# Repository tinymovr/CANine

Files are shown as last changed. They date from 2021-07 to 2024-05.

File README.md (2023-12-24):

# CANine Schematics, Drawings and Firmware

## Schematics and Drawings

CANine is Certified Open Source Hardware

[OSHW] GR000007 | Certified open source hardware | oshwa.org/cert

## Firmware

USB CDC firmware for the CANine USB⟷CAN Bus adapter. This firmware is based on slcan but gets rid of the Virtual Com Port cruft, resulting in leaner communication on all platforms, and especially on Windows. Most slcan commands are the same, but the CAN frame size is fixed and data is transmitted as binary (instead of ascii in slcan).

This firmware should be compatible with CANable adapters, but has not been tested.

[Documentation](https://canine.readthedocs.io/en/latest/)

### Flashing

We now offer [a simple Web-based firmware update service](https://tinymovr.github.io/CANine/). Instructions are available on the page. Chrome and Edge are supported.

### Using

This firmware is compatible with python-can through the corresponding [plugin available on PyPi](https://pypi.org/project/python-can-canine/).

This firmware is compatible with Tinymovr. To use with Studio, add the command line parameter `--bus=canine` when launching.

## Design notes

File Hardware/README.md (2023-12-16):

# CANine CAN Adapter

This is a USB Type-C <-> CAN Bus adapter. Itself it is an adaptation of the [CANable board](https://canable.io/). It features a 2.54mm screw terminal, a 4-pin JST-GH connector, and a 2.54mm header. In addition, it features a convenient DIP switch for setting CAN termination resistor and boot mode.

This design is released under the original CANable license.

This directory also includes an STL model for a compact 3D printable case.

There is also an [alternative case design for the legacy CANine](https://github.com/ThotAlion/BLDC-design-help/tree/main/STL/USBCANBox) by ThotAlion.

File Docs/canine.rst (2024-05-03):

**********************
CANine adapter
**********************

Introduction
############

This is a USB Type-C <-> CAN Bus adapter. Itself it is an adaptation of the [CANable board](https://canable.io/). It features a 5.08mm screw terminal, a 4-pin JST-GH connector, and a 2.54mm header. In addition, it features a convenient DIP switch for setting CAN termination resistor and boot mode.

CANine includes the following hardware:

* STM32F042C6 MCU
* MCP2551 CAN Bus Transceiver
* JST-GH/5.08mm Screw Terminal/2.54mm Pin header CAN interfaces
* USB Type-C (v2) / micro (v1) interface

This design is Open Source, released under the original CANable license.

Hardware Configuration
######################

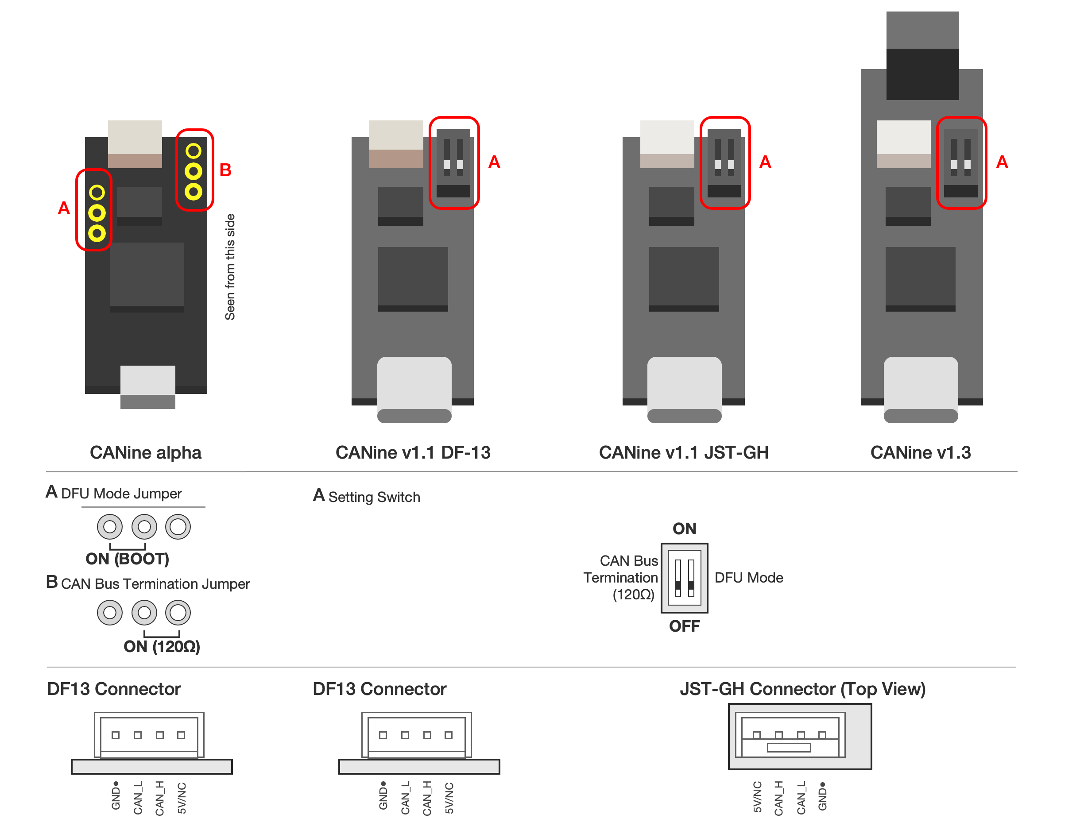
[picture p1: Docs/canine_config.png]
CANine hardware configuration diagram


.. warning::
   * Do not change the position of the DIP switches while the adapter is powered. First remove power, perform your change, and power back on.

CAN Termination Resistor
------------------------

CANine includes a termination resistor to ease the setup of a CAN Bus network. If CANine is a terminal node in the network, you should enable the 120Ohm termination resistor via the onboard DIP switch. In small setups with a few nodes and short wires, it is enough to enable just a single termination resistor, either on the CANine or on a single Tinymovr.

Flashing Firmware
#################

CANine comes pre-flashed with `slcan <https://python-can.readthedocs.io/en/master/interfaces/slcan.html>`_.

Hardware Preparation
--------------------

Unplug the CANine adapter from USB. Flip the DFU switch to the ON position. Plug the adapter back into USB. The device will appear as a ST DFU Device, and allow firmware flashing. Once firmware flashing is complete, unplug the device and return the switch to the OFF position.

CANine Firmware
---------------

To try the CANine firmware, we offer `a simple Web-based firmware update service <https://tinymovr.github.io/CANine/>`_. Instructions are available on the page. Chrome and Edge are supported.

Python-Can Compatibility
************************

We offer a `python-can plugin available on PyPi <https://pypi.org/project/python-can-canine>`_, which allows use of CANine with python-can. The plugin is easily installable via pypi:

.. code-block:: console

    pip install python-can-canine

To use with Tinymovr Studio, add the command line parameter `--bus=canine` when launching.

In your scripts, use the CANine interface through a simple import:

.. code-block:: python

    import can
    from canine import CANineBus
    
    bus = can.Bus(interface="canine", bitrate=1000000)

Additional Windows Requirements
*******************************

You will need to install the libusb driver for your CANine. This is most easily done using `Zadig <https://zadig.akeo.ie>`_

Additional Macos Requirements
*****************************

You will need to install libusb. This can be easily done using `Homebrew <https://brew.sh>`_:

.. code-block:: console

    brew install libusb

In ARM-based Macs you may also need to link the homebrew library install path to the fallback path `/lib`. This can be done with the following command:

.. code-block:: console

    ln -s /opt/homebrew/lib ~/lib

Additional Linux requirements
*****************************

You will need to add udev rules for CANine:

.. code-block:: console

    sudo bash -c 'echo -e "SUBSYSTEM==\"usb\", ATTR{idVendor}==\"0483\", ATTR{idProduct}==\"c1b0\", MODE=\"0666\", SYMLINK+=\"canine_usb\"" > /etc/udev/rules.d/11-canine.rules'
    sudo udevadm control --reload-rules && sudo udevadm trigger

To have the rules loaded at every boot, add the command to your `.bashrc`.

slcan & CANdlelight Firmware
----------------------------

CANine is compatible with both slcan as well as candlelight firmware. If you would like to revert to these firmwares, the easiest solution is to use the `canable updater <https://canable.io/updater/>`_. Similarly to the CANine flasher, this updater works directly from within the browser. Chrome and Edge are supported.

3D Printed Case Assembly
########################

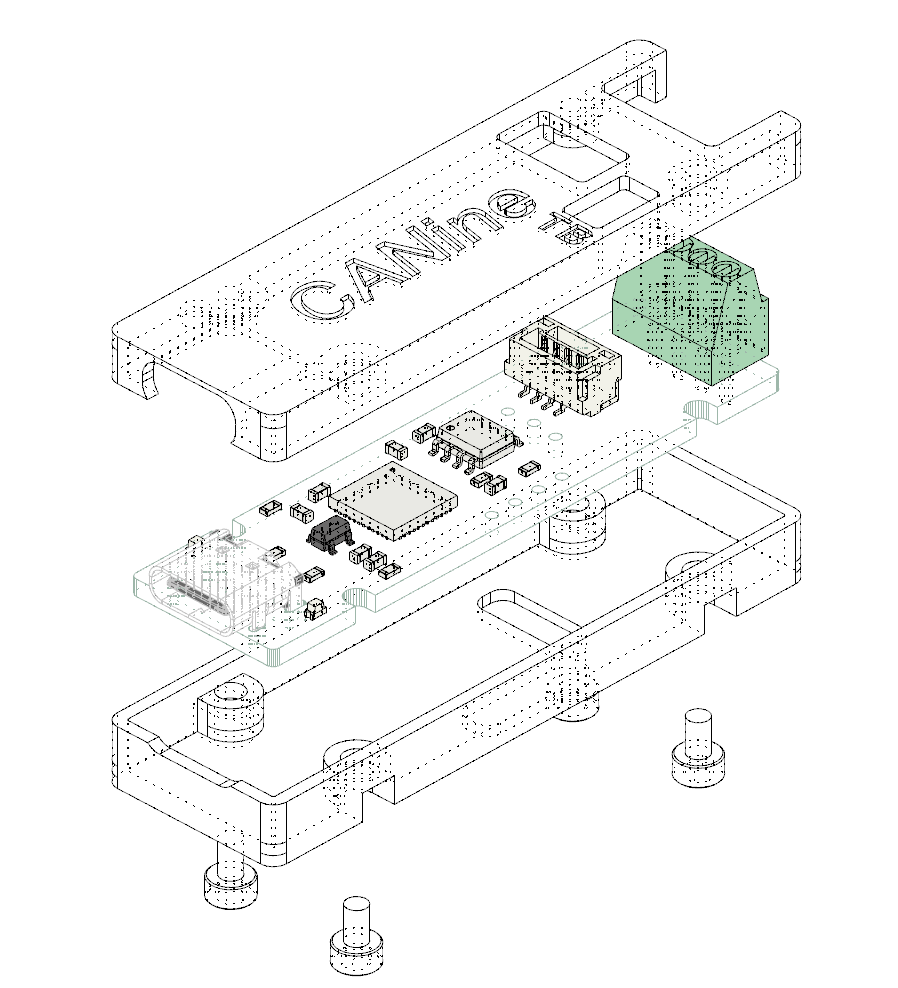
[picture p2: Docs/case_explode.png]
CANine 3D Printed Case


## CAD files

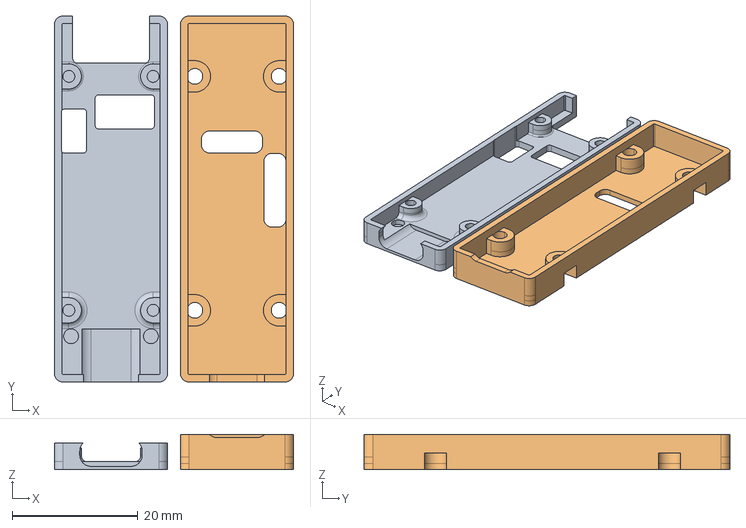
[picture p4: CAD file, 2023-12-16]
Hardware/CANine Cover.stp
38.1 x 58.2 x 5.58 mm

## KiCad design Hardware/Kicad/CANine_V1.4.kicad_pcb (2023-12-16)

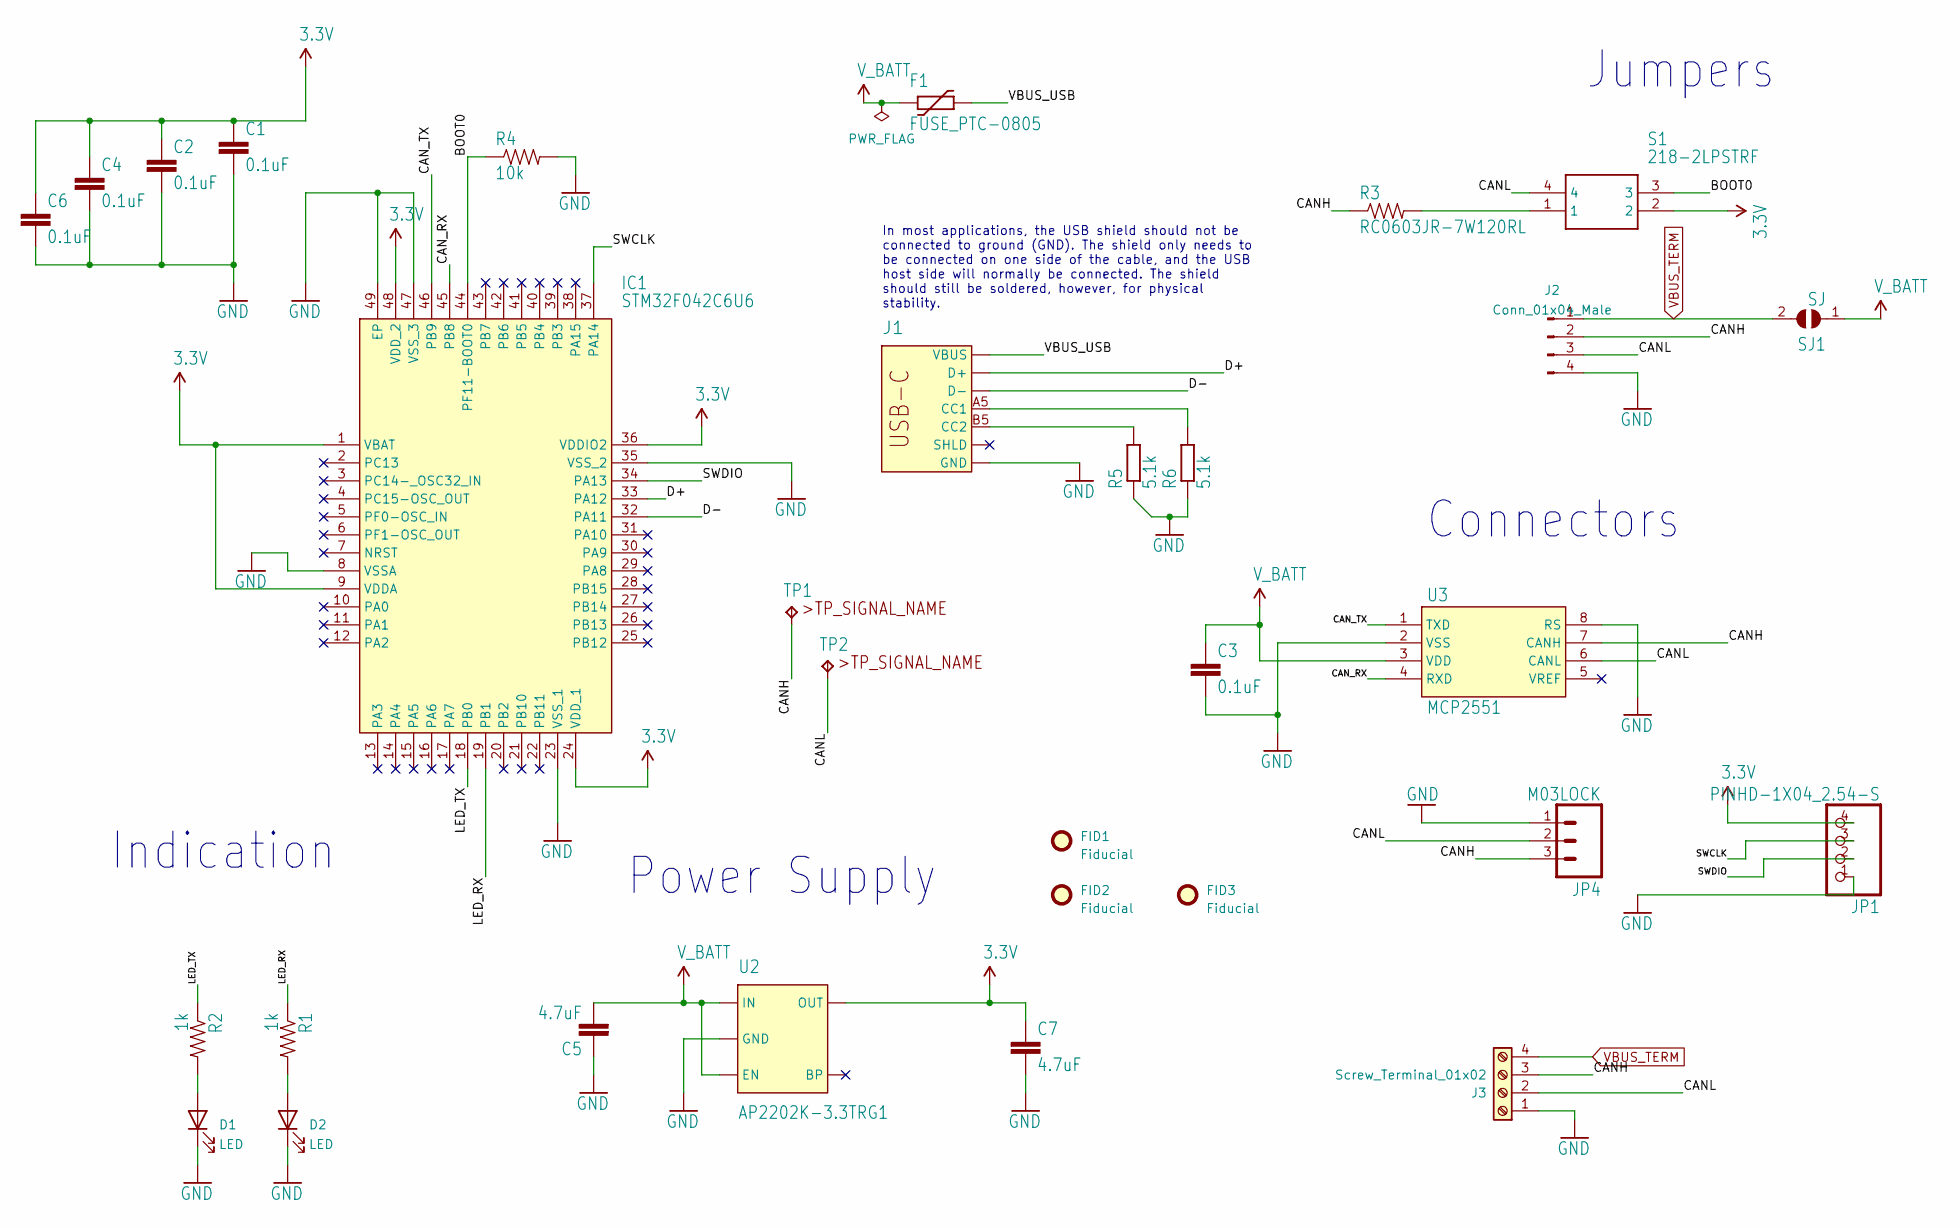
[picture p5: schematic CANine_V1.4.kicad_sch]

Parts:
C1, C2, C3, C4, C6: 0.1uF; C_0603_1608Metric
C5, C7: 4.7uF; C_0603_1608Metric
D1, D2: LED; LED_0603_1608Metric
F1: FUSE_PTC-0805; PTC0805
FID1, FID2, FID3: Fiducial; Fiducial_0.75mm_Mask1.5mm
IC1: STM32F042C6U6; QFN-48-1EP_7x7mm_P0.5mm_EP5.6x5.6mm
J1: SPARKFUN-CONNECTORS_USB_C16PIN; SPARKFUN-CONNECTORS_USB-C-16P
J2: Conn_01x04_Male; JST_GH_BM04B-GHS-TBT_1x04-1MP_P1.25mm_Vertical
J3: Screw_Terminal_01x02; TerminalBlock_Phoenix_MPT-0,5-4-2.54_1x04_P2.54mm_Horizontal
JP1: PINHD-1X04_2.54-S; 1X04-S
JP4: M03LOCK; 1X03_LOCK
R1, R2: 1k; R_0603_1608Metric
R3: RC0603JR-7W120RL; R_0603_1608Metric
R4: 10k; R_0603_1608Metric
R5, R6: 5.1k; R_0603_1608Metric
S1: 218-2LPSTRF; 2182LPSTRF
SJ1: SJ
TP1, TP2: TPTP16R; TP16R
U2: AP2202K-3.3TRG1; SOT-23-5
U3: MCP2551; SOIC-8_3.9x4.9mm_P1.27mm

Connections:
3.3V: C1.1, C2.1, C4.1, C6.1, C7.1, IC1.1 (VBAT), IC1.9 (VDDA), IC1.24 (VDD_1), IC1.36 (VDDIO2), IC1.48 (VDD_2), JP1.4, S1.2, U2.5 (OUT)
/BOOT0: IC1.44 (PF11-BOOT0), R4.1, S1.3
/CANH: J2.2, J3.3, JP4.3, R3.1, TP1.TP, U3.7 (CANH)
/CANL: J2.3, J3.2, JP4.2, S1.4, TP2.TP, U3.6 (CANL)
/CAN_RX: IC1.45 (PB8), U3.4 (RXD)
/CAN_TX: IC1.46 (PB9), U3.1 (TXD)
/D+: IC1.33 (PA12), J1.A6 (D+), J1.B6 (D+)
/D-: IC1.32 (PA11), J1.A7 (D-), J1.B7 (D-)
/LED_RX: IC1.19 (PB1), R1.1
/LED_TX: IC1.18 (PB0), R2.1
/SWCLK: IC1.37 (PA14), JP1.3
/SWDIO: IC1.34 (PA13), JP1.2
/VBUS_USB: F1.2, J1.VBUS1 (VBUS), J1.VBUS2 (VBUS)
GND: C1.2, C2.2, C3.2, C4.2, C5.1, C6.2, C7.2, D1.1 (K), D2.1 (K), IC1.8 (VSSA), IC1.23 (VSS_1), IC1.35 (VSS_2), IC1.47 (VSS_3), IC1.49 (EP), J1.GND, J1.GND2 (GND), J2.4, J3.1, JP1.1, JP4.1, R4.2, R5.1, R6.1, U2.2 (GND), U3.2 (VSS), U3.8 (RS)
unnamed: D1.2 (A), R2.2
unnamed: D2.2 (A), R1.2
unnamed: J1.A5 (CC1), R6.2
unnamed: J1.B5 (CC2), R5.2
unnamed: R3.2, S1.1
VBUS_TERM: J2.1, J3.4, SJ1.2
V_BATT: C3.1, C5.2, F1.1, SJ1.1, U2.1 (IN), U2.3 (EN), U3.3 (VDD)

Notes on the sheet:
Jumpers
In most applications, the USB shield should not be connected to ground (GND). The shield only needs to be connected on one side of the cable, and the USB host side will normally be connected. The shield should still be soldered, however, for physical stability.
Connectors
Indication
Power Supply

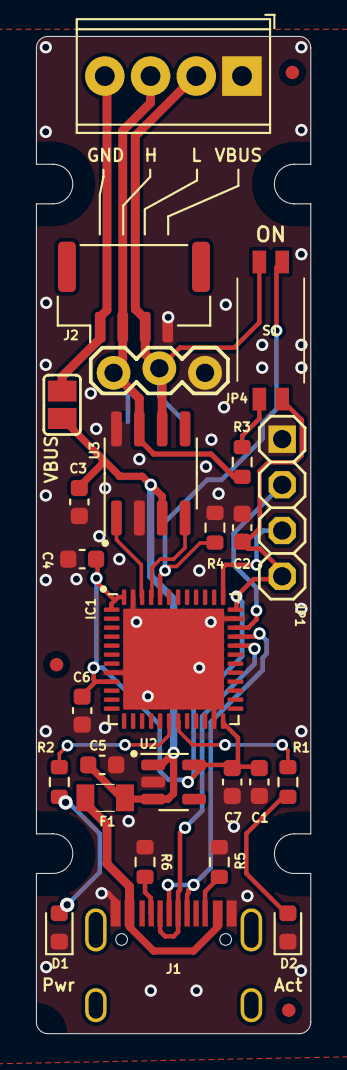
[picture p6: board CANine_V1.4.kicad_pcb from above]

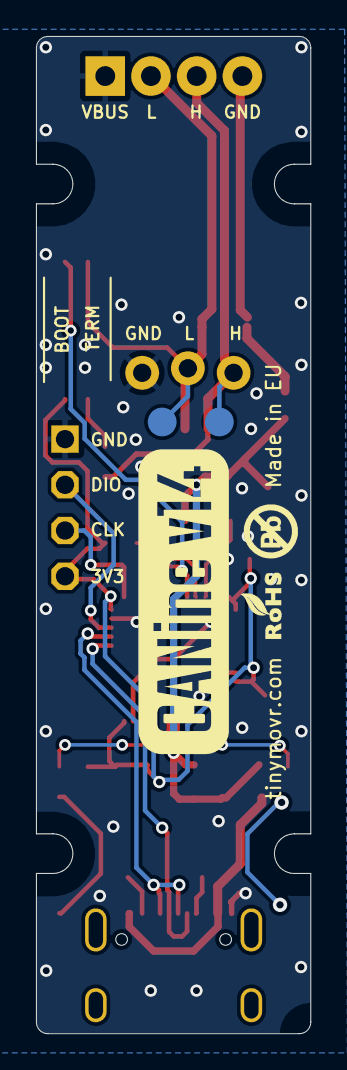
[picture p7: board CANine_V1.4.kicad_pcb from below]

Board: 2 copper layers, 15.2 x 55.4 mm, 31 parts (2 on the bottom side), 21 nets.

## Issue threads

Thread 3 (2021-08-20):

Raise can0 network with Canine on Linux

ThotAlion, 2021-08-20:
We did upgrade the firmware of the CANine dongle.
After plugging the dongle on the robot, no can0 interface appear on 'ifconfig'
Is there a command line to execute to create this network entry ? (like candlelight?) or is it automatic ?
And if we have two dongles, how to differenciate them ? Would you have an example or explain in the doc the process to create such udev rule ?

Thank you for your help,

yconst, 2021-08-20:
When you mention "upgraded", I assume you mean flashing the Candlelight firmware, correct? Because the firmware hosted in this repo is not compatible with socketcan, it is usb only.

You can follow the guide in the Canable page: https://canable.io/getting-started.html#alt-firmware

ThotAlion, 2021-08-20:
No, I mean I wanted to flash the firmware on this repo. I though it was a socketcan.
Therefore, this firmware shall open a /dev/ttyUSBX file ?
Thanks again.

yconst, 2021-08-21:
It only enumerates as a USB device, there is no serial interface. Currently it is supported by our [fork of the python-can library](https://github.com/tinymovr/python-can) (the `develop` branch). It's not yet tested on Linux (Windows and Macos works), but it should work without an issue.

You can set `--bustype=canine` for Tinymovr studio to use this protocol. In fact, if you pip install studio from the [main branch](https://github.com/tinymovr/Tinymovr), you'll get the forked python-can library installed automatically.

yconst, 2023-04-24:
Closing this as inactive

Closed 2023-04-24.

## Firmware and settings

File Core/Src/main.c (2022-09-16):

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
/* Includes ------------------------------------------------------------------*/
#include "main.h"
#include "usb_device.h"

/* USER CODE BEGIN Includes */
#include "stm32f0xx.h"
#include "stm32f0xx_hal.h"

#include "usb_device.h"
#include "usbd_cdc_if.h"
#include "can.h"
#include "slcan.h"
#include "led.h"
#include "error.h"
/* USER CODE END Includes */

CAN_HandleTypeDef hcan;

void SystemClock_Config(void);
static void MX_GPIO_Init(void);
static void MX_CAN_Init(void);
/**
  * @brief  The application entry point.
  * @retval int
  */
int main(void)
{
    /* MCU Configuration--------------------------------------------------------*/

    /* Reset of all peripherals, Initializes the Flash interface and the Systick. */
    HAL_Init();

    /* USER CODE BEGIN Init */
    can_init();
    /* USER CODE END Init */

    /* Configure the system clock */
    SystemClock_Config();

    /* Initialize all configured peripherals */
    MX_GPIO_Init();
    // MX_CAN_Init();
    MX_USB_DEVICE_Init();
    /* USER CODE BEGIN 2 */

    HAL_GPIO_WritePin(LED_GREEN, 1);
    led_blue_blink(2);

    // Storage for status and received message buffer
    CAN_RxHeaderTypeDef rx_msg_header;
    uint8_t rx_msg_data[8] = {0};
    uint8_t msg_buf[SLCAN_MTU];

    /* USER CODE END 2 */

    /* Infinite loop */
    /* USER CODE BEGIN WHILE */
    while (1)
    {
        cdc_process();
        led_process();
        can_process();

        // If CAN message receive is pending, process the message
        if(is_can_msg_pending(CAN_RX_FIFO0))
        {
            // If message received from bus, parse the frame
            if (can_rx(&rx_msg_header, rx_msg_data) == HAL_OK)
            {
                uint16_t msg_len = slcan_parse_frame((uint8_t *)&msg_buf, &rx_msg_header, rx_msg_data);

                // Transmit message via USB-CDC
                if(msg_len)
                {
                    CDC_Transmit_FS(msg_buf, msg_len);
                }
            }
        }
        /* USER CODE END WHILE */

        /* USER CODE BEGIN 3 */
    }
    /* USER CODE END 3 */
}

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


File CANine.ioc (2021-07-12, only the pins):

Mcu.UserName=STM32F042C6Tx
PA13.Signal=SYS_SWDIO
PA12.Signal=USB_DP
PB9.Signal=CAN_TX
PB1.Signal=GPIO_Output
PA11.Signal=USB_DM
PA14.Signal=SYS_SWCLK
PB8.Signal=CAN_RX
PB0.Signal=GPIO_Output

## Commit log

2021-07-12 optimize frame parsing
2021-07-18 Add vendor and device ids (#1)
    * Add vendor and device ids
    * Add add vendor and device ids
    * Use vendor and device ids
2021-07-31 migrate hardware
    [CANine.brd, CANine.sch, case.stl]
2022-09-13 device connecting
2022-10-12 print binary data
2022-10-30 add latest hardware revision
    [CANine.brd, CANine.sch, CANine_v2.csv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]
2023-12-16 update hardware files
    [CANine Cover.stp, CANine_V1.4.kicad_pcb, CANine_V1.4.kicad_sch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]
2024-05-03 add 3D printed case diagram

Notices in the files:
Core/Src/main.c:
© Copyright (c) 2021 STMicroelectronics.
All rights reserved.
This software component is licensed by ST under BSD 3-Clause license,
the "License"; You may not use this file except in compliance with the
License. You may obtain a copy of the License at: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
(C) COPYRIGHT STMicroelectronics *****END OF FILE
